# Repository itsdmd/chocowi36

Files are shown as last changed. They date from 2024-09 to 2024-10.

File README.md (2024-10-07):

# chocowi36

> A 36-key, low profile, wireless, split keyboard. Derived from [davidphilipbarr/Choc-Spaced-Corne](https://github.com/davidphilipbarr/Choc-Spaced-Corne), with the original design based on [Foostan's Corne](https://github.com/foostan/crkbd).

Finished build

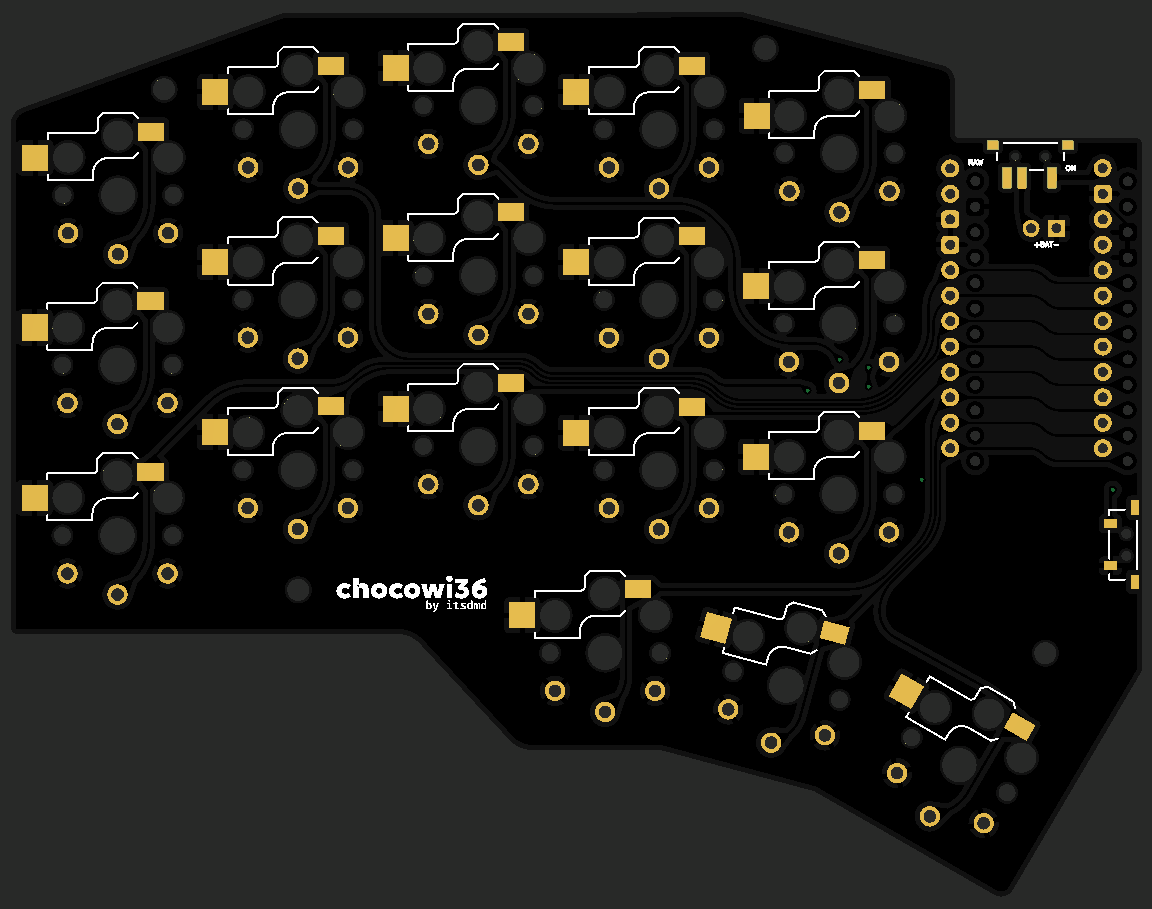
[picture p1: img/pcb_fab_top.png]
chocowi36 PCB Top - JLCPCB render
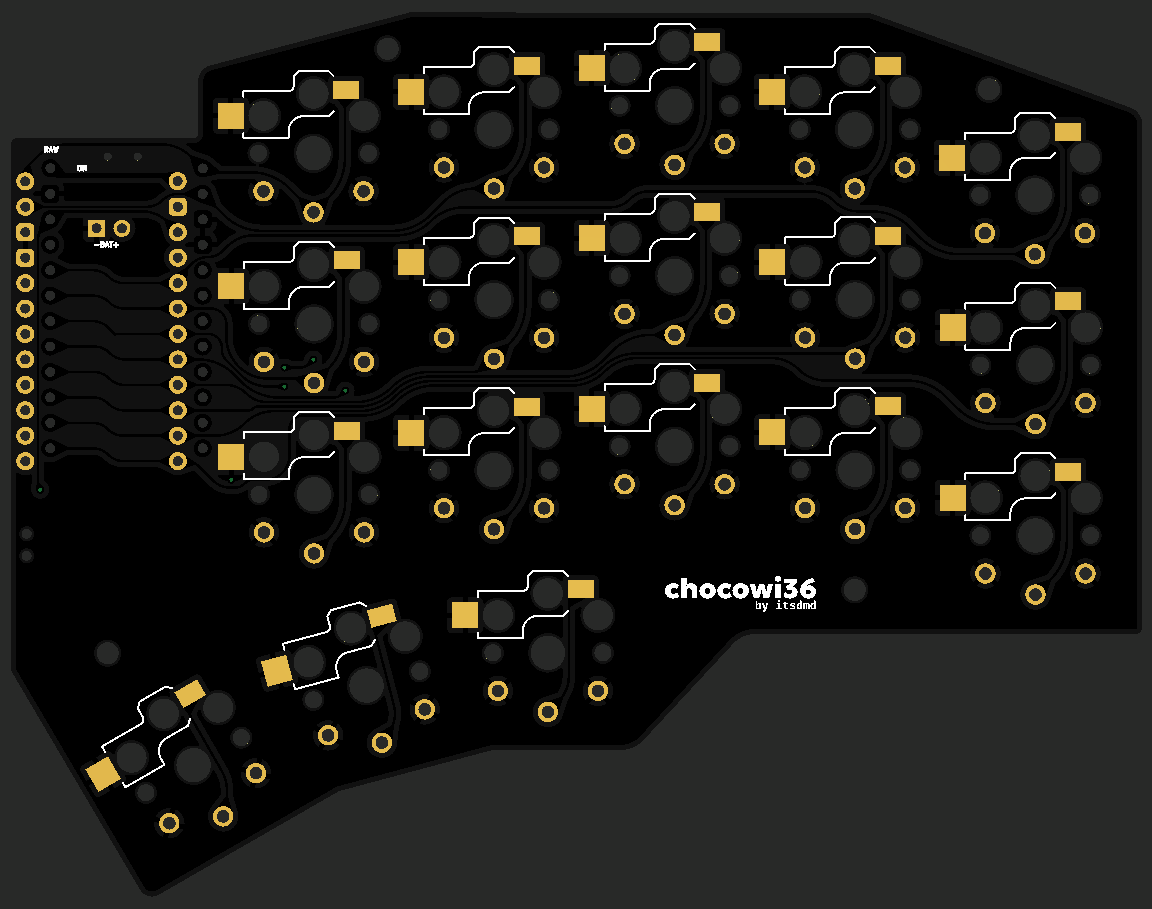
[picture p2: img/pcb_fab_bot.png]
chocowi36 PCB Bottom - JLCPCB render
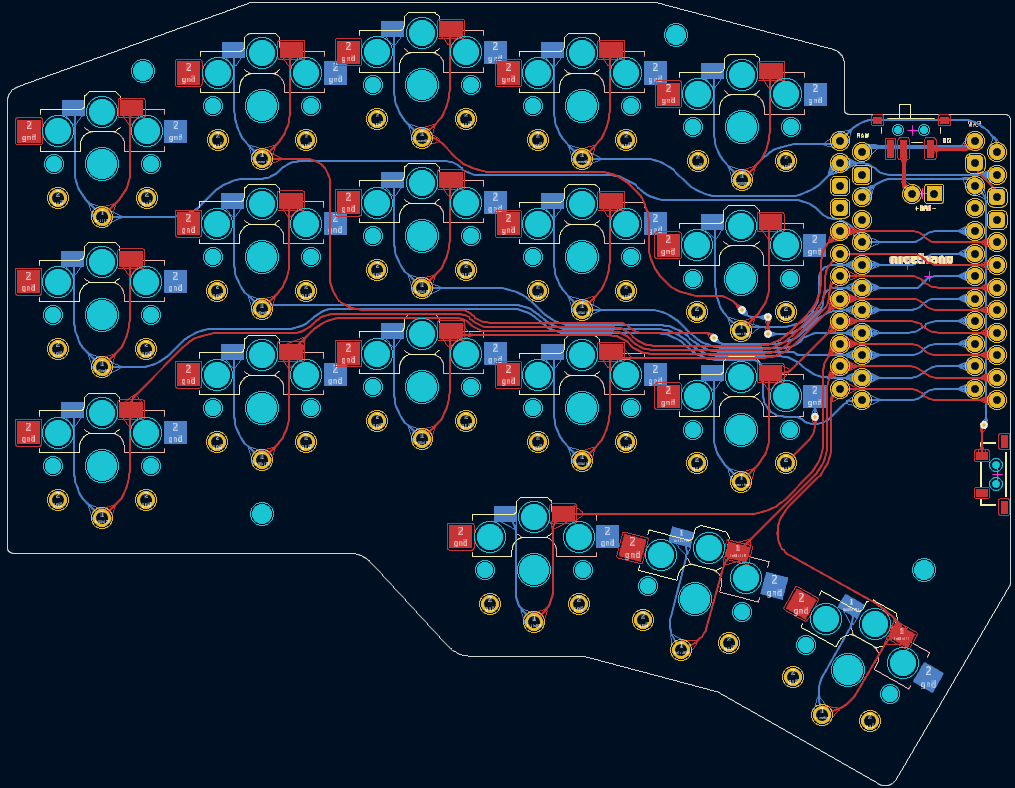
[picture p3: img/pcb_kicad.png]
chocowi36 PCB - KiCad render


## Changes

-   The PCB shape, dimensions and mounting holes' position are modified to personal preferences.
-   Battery onboard connector is replaced with through hole pads for better flexibility. Power switch is connected to the positive terminal of the battery instead of ground.
-   The outermost thumb key has been changed to a 1u key, and the splayed angle of the thumb cluster has been increased to 15 degrees.
-   Allow the nice!nano to be mounted with the USB port facing down for both halves for better MCB protection.
-   Support both hotswap and soldered switches. Only Choc v1 switches are supported.

## Case

The case for the keyboard can be found here: [OnShape document](https://cad.onshape.com/documents/46b39ce86a53def7590272f1/w/488db377576b09efc6e15f6f/e/8a81a5fcc0753b2088ec2435)

Finished build - Folded

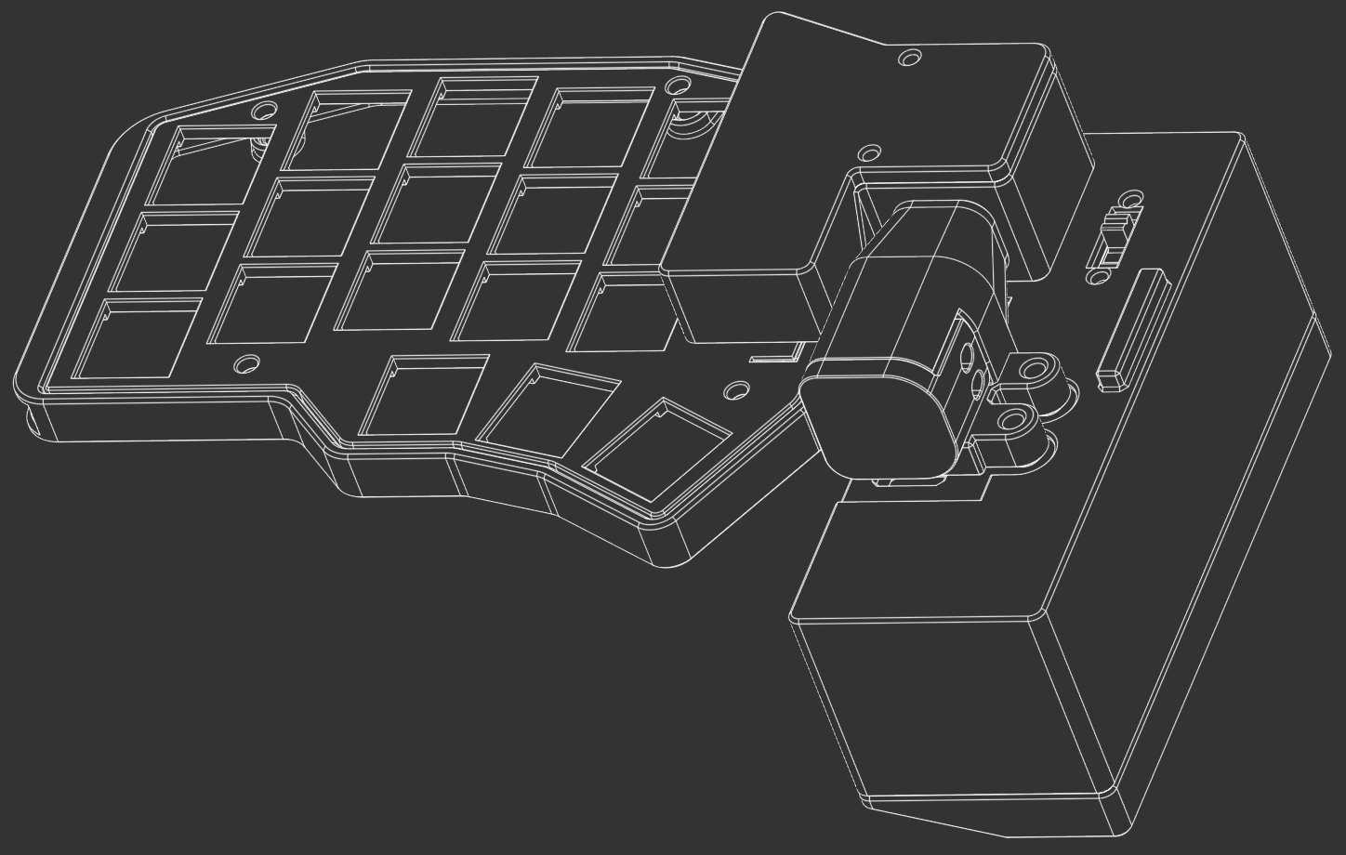
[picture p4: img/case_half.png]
chocowi36 Case - OnShape render
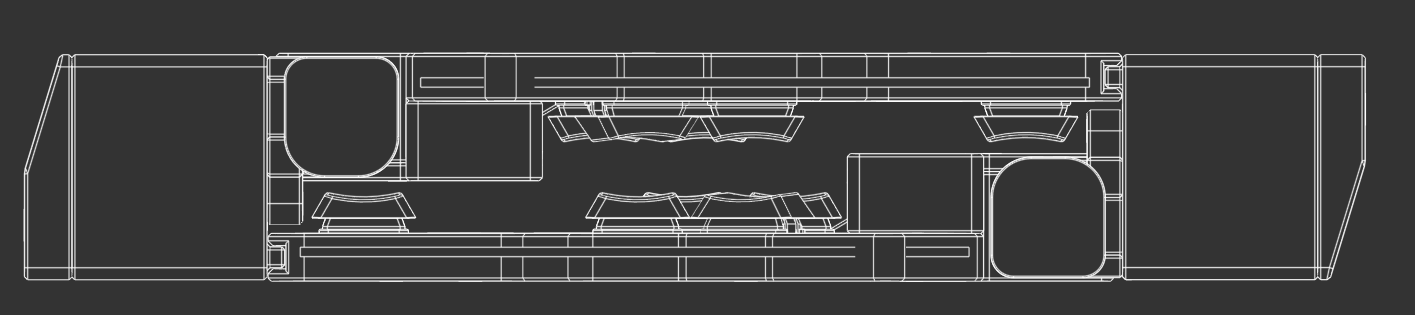
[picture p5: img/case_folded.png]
chocowi36 Case Folded - OnShape render


This case features a 5.5x2.1 DC power jack for connecting to a detachable Li-Ion battery enclosure. The provided enclosure is designed for storing a 21700 battery with a protection PCB attached to it. This enclosure can act as a tenting mechanism, or for locking the two keyboard halves in place when folded for travelling. Most parameters can be _slightly_ adjust without breaking the whole thing. The screw holes are 3.0mm in diameter (for housing M2 heat inserts), and default tolerance is 0.3-0.5mm.

## Firmware

ZMK shield definition of chocowi36 can be obtained [here](https://github.com/itsdmd/zmk-dongle/tree/N!N_v2/config/boards/shields/chocowi36). Please note that the definition files are written for the keyboard to be used with a third nice!nano as the central/dongle.

The provided files should only act as the boilerplate, please adjust the configurations according to your personal needs and preferences. You can create your own repo using the [template](https://github.com/itsdmd/zmk-dongle) and make further modifications.

## Notes

There are two versions of the PCB, one with [straight traces](./pcb/gerber/straight/straight.zip) and one with [curved traces](./pcb/gerber/rounded/rounded.zip). There are no major differences between the two, mostly just aesthetics.

## Disclaimer

This is a **personal project** and not affiliated with the original authors. The gerber file has been checked against JLCPCB's DFM checker and no critical error was found. All files (including firmware) are provided as-is, **without any warranty or support**.

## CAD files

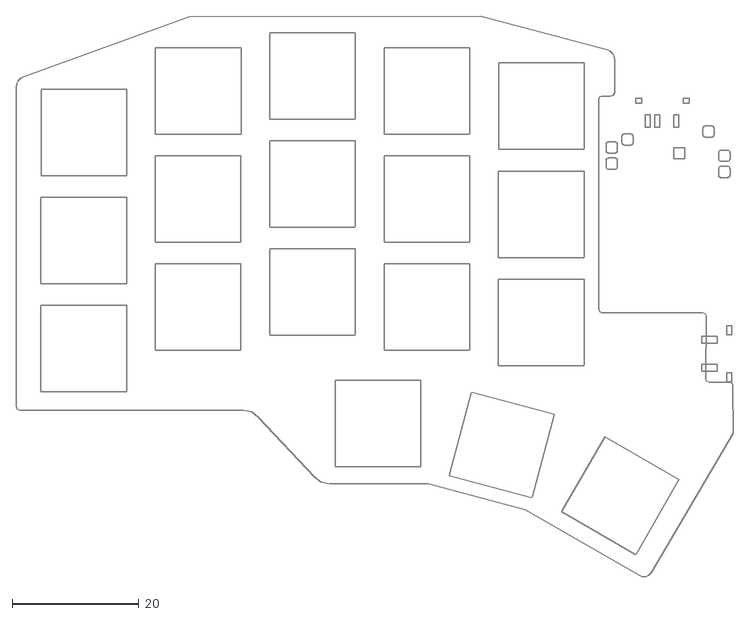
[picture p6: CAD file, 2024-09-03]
case/components/plate-brd.dxf
113.0 x 88.3

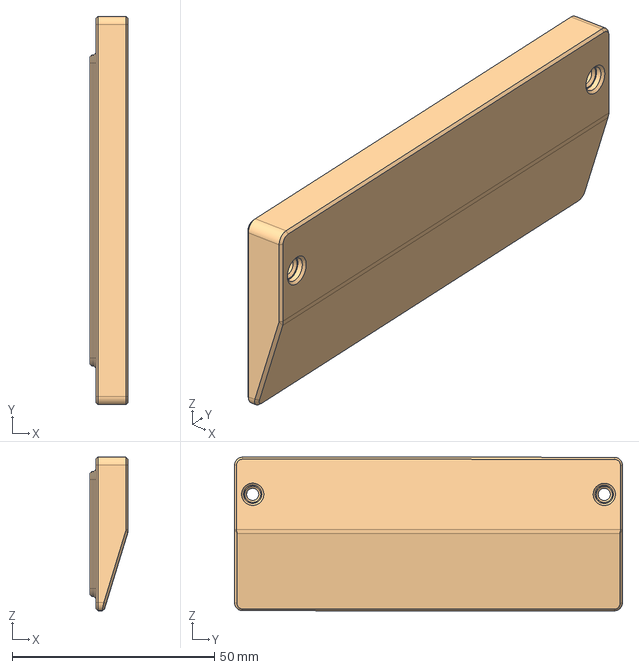
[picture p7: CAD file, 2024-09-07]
case/step/BattPack - Container Cover.step
9.53 x 96.0 x 38.0 mm

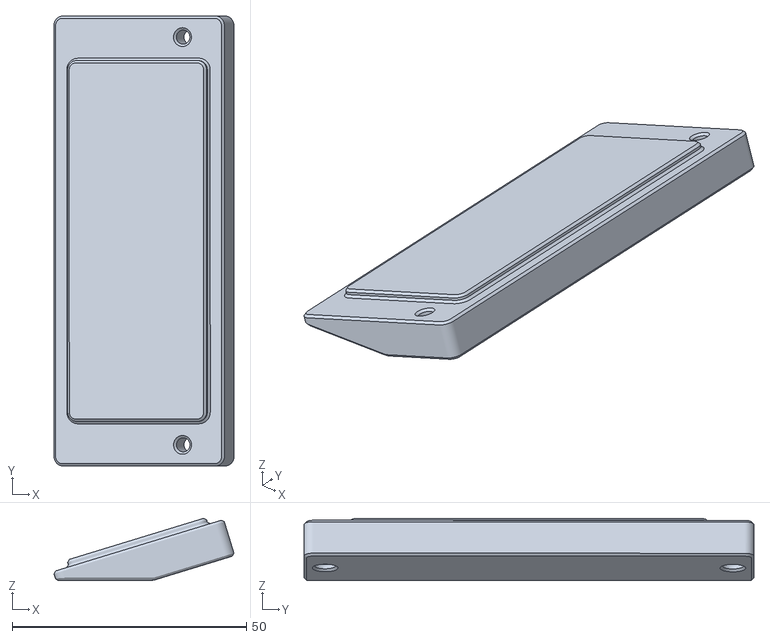
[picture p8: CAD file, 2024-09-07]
case/stl/L - BattPack - Container Cover.stl
38.4 x 96.0 x 13.3

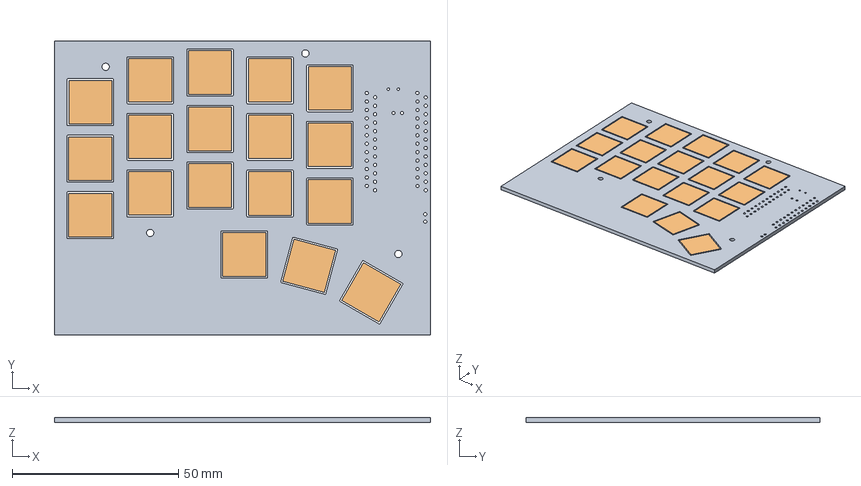
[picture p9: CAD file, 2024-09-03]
case/components/chocowi36-plate.step
113.1 x 88.4 x 1.60 mm

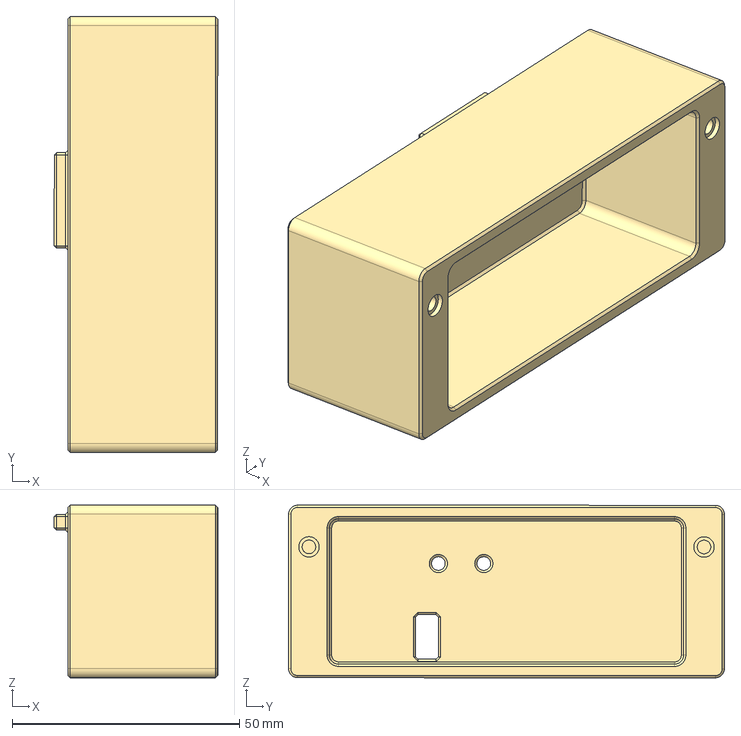
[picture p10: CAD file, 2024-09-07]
case/step/BattPack - Container.step
36.0 x 96.0 x 38.0 mm

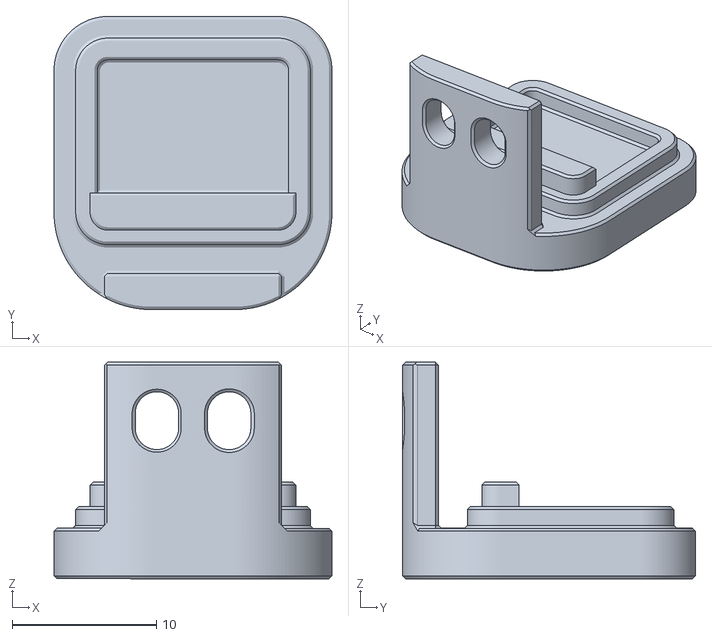
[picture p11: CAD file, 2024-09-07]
case/stl/L - BattPack - Connector Cover.stl
19.3 x 20.3 x 15.0

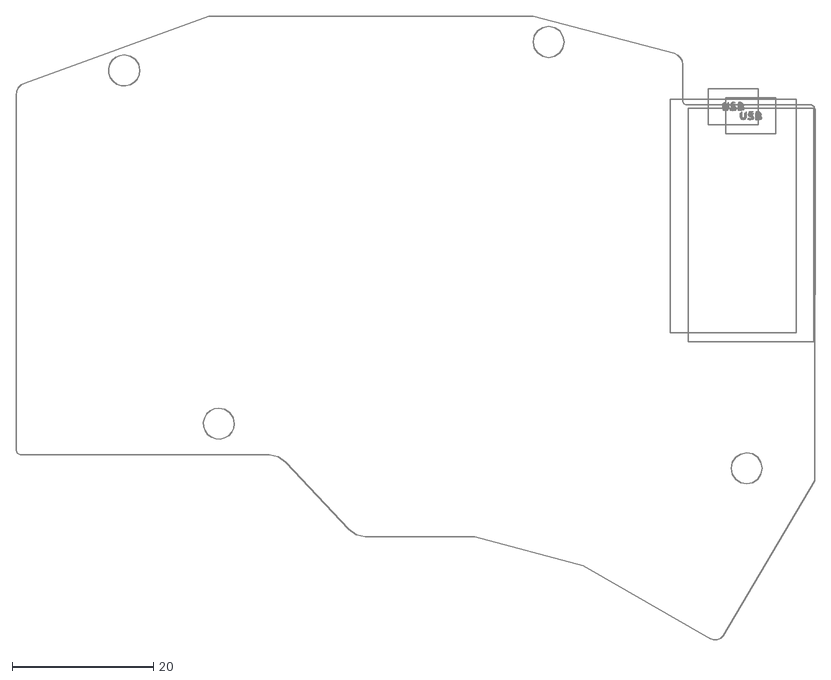
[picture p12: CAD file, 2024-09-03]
case/components/chocowi36-brd.dxf
113.1 x 88.3

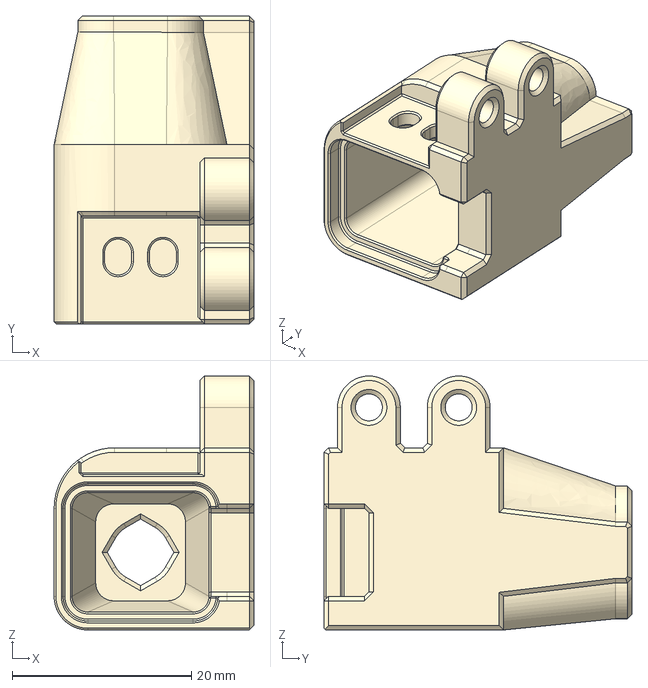
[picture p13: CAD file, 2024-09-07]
case/step/BattPack - Connector.step
22.3 x 34.3 x 28.3 mm

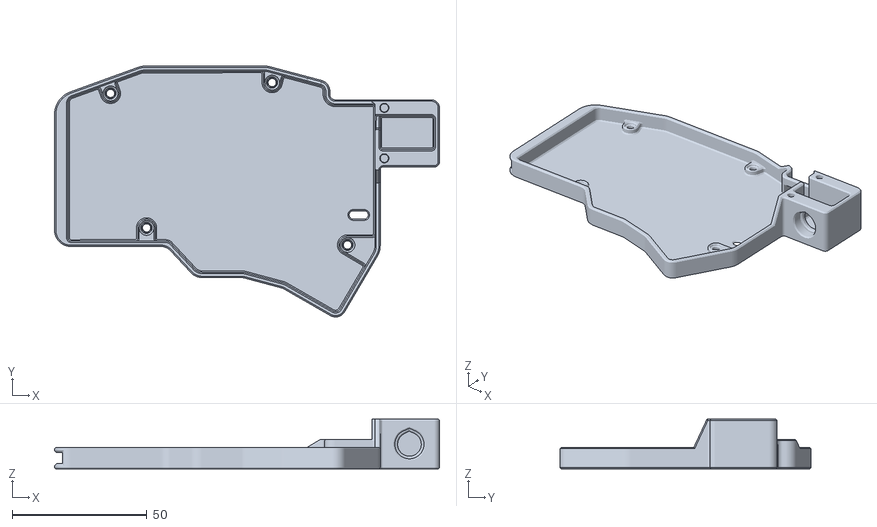
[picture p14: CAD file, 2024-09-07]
case/stl/L - Case.stl
143.1 x 93.3 x 18.5

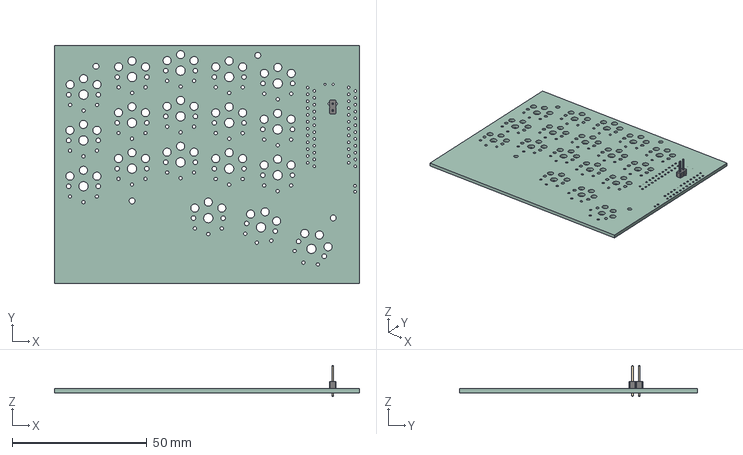
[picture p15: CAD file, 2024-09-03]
case/components/chocowi36.step
113.2 x 88.4 x 11.5 mm
PinHeader_1x02_P254mm_Vertical
chocowi36_PCB

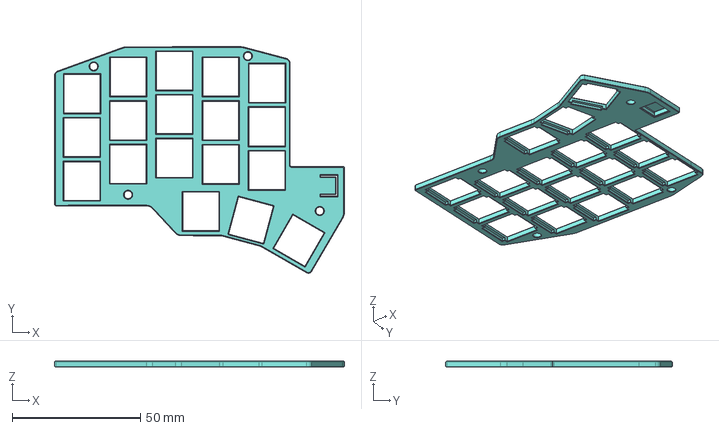
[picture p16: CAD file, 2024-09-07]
case/step/Plate.step
113.0 x 88.3 x 2.30 mm

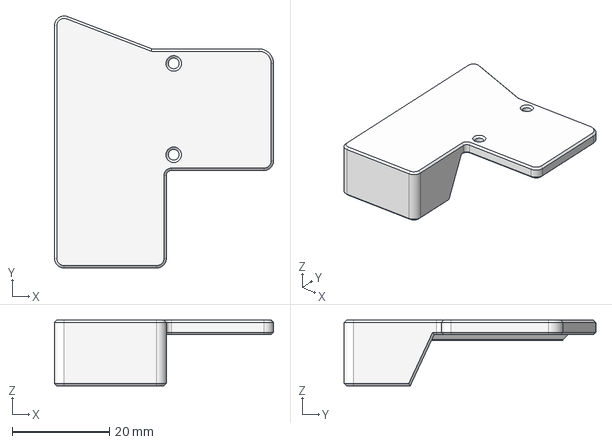
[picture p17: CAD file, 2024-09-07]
case/step/MCB Cover.step
45.0 x 51.7 x 13.5 mm

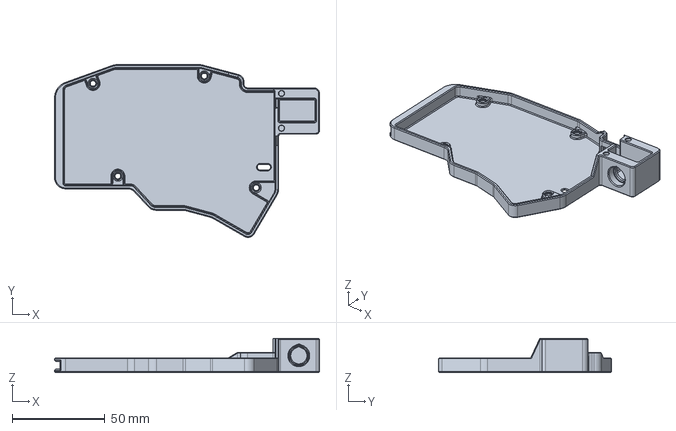
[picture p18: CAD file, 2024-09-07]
case/step/Case.step
143.1 x 93.3 x 18.5 mm

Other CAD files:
case/stl/L - BattPack - Container.stl
case/stl/L - Plate.stl
case/stl/R - BattPack - Container Cover.stl
case/step/BattPack - Connector Cover.step
case/stl/R - BattPack - Container.stl
case/stl/L - BattPack - Connector.stl
case/stl/L - MCB Cover.stl
case/stl/R - BattPack - Connector Cover.stl
case/stl/R - BattPack - Connector.stl
case/stl/R - Case.stl
case/stl/R - MCB Cover.stl
case/stl/R - Plate.stl

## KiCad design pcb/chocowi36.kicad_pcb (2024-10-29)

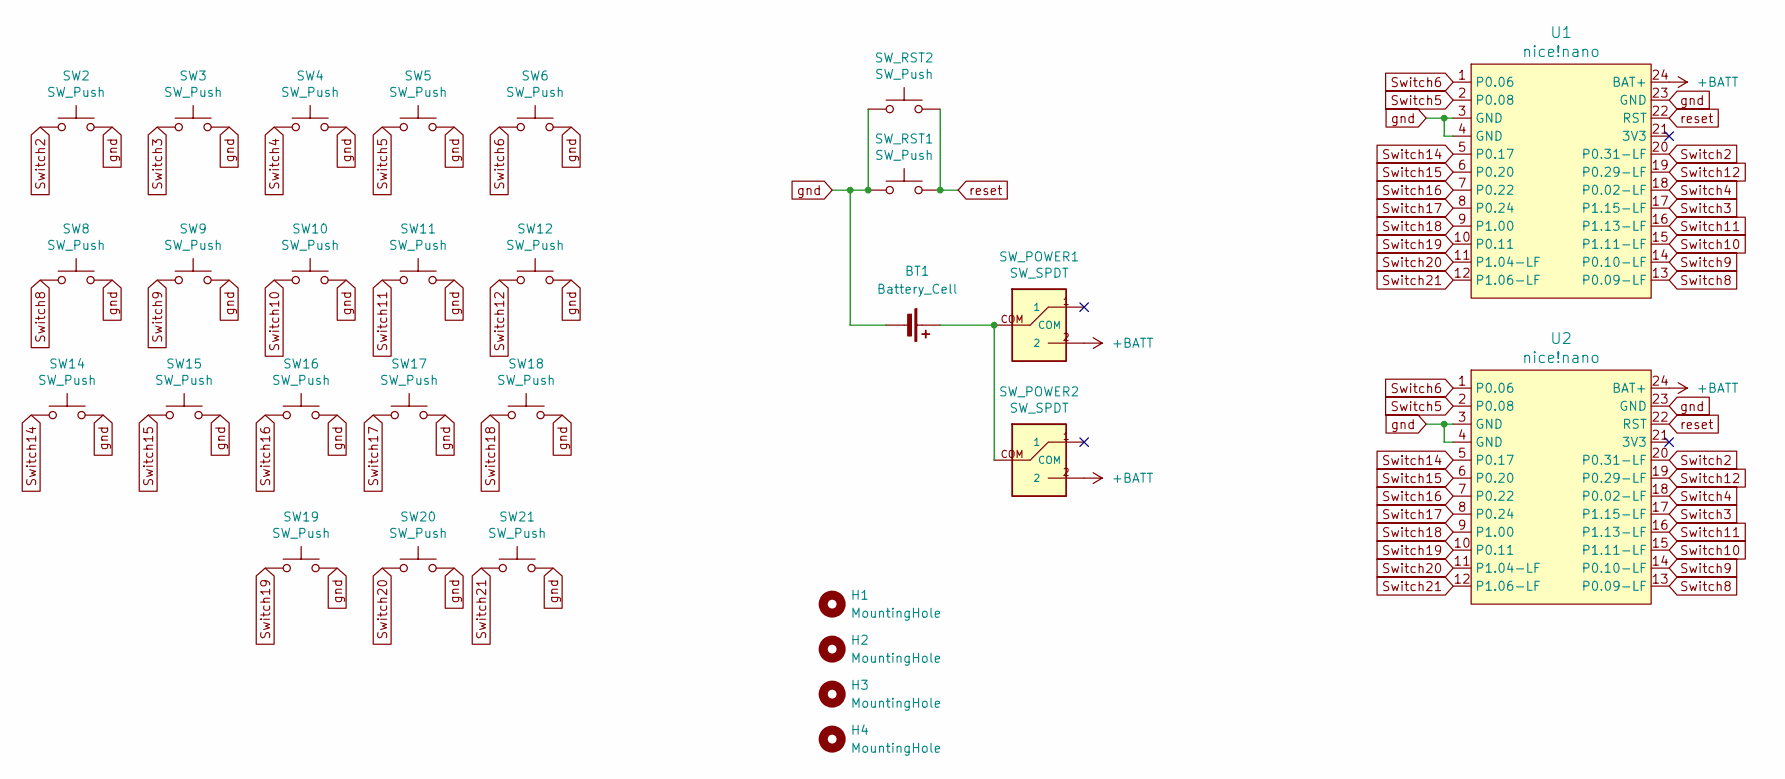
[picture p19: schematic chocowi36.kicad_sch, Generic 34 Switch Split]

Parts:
BT1: Battery_Cell; Battery_Pads-dual-side
H1, H2, H3, H4: MountingHole; MountingHole_2.2mm_M2
SW2, SW3, SW4, SW5, SW6, SW8, SW9, SW10, SW11, SW12, SW14, SW15, SW16, SW17, SW18, SW19, SW20, SW21: SW_Push; KS_Socket_Choc_optional_reversible
SW_POWER1, SW_POWER2: SW_SPDT; SW-S_MSK-12C02
SW_RST1, SW_RST2: SW_Push; SW-T_SPST_TL3342
U1, U2: nice!nano; MCB_nice-nano_flip

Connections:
+BATT: SW_POWER1.2, SW_POWER2.2, U1.24 (BAT+), U2.24 (BAT+)
unnamed: BT1.1 (+), SW_POWER1.COM, SW_POWER2.COM
Switch2: SW2.1, U1.20 (P0.31-LF), U2.20 (P0.31-LF)
Switch3: SW3.1, U1.17 (P1.15-LF), U2.17 (P1.15-LF)
Switch4: SW4.1, U1.18 (P0.02-LF), U2.18 (P0.02-LF)
Switch5: SW5.1, U1.2 (P0.08), U2.2 (P0.08)
Switch6: SW6.1, U1.1 (P0.06), U2.1 (P0.06)
Switch8: SW8.1, U1.13 (P0.09-LF), U2.13 (P0.09-LF)
Switch9: SW9.1, U1.14 (P0.10-LF), U2.14 (P0.10-LF)
Switch10: SW10.1, U1.15 (P1.11-LF), U2.15 (P1.11-LF)
Switch11: SW11.1, U1.16 (P1.13-LF), U2.16 (P1.13-LF)
Switch12: SW12.1, U1.19 (P0.29-LF), U2.19 (P0.29-LF)
Switch14: SW14.1, U1.5 (P0.17), U2.5 (P0.17)
Switch15: SW15.1, U1.6 (P0.20), U2.6 (P0.20)
Switch16: SW16.1, U1.7 (P0.22), U2.7 (P0.22)
Switch17: SW17.1, U1.8 (P0.24), U2.8 (P0.24)
Switch18: SW18.1, U1.9 (P1.00), U2.9 (P1.00)
Switch19: SW19.1, U1.10 (P0.11), U2.10 (P0.11)
Switch20: SW20.1, U1.11 (P1.04-LF), U2.11 (P1.04-LF)
Switch21: SW21.1, U1.12 (P1.06-LF), U2.12 (P1.06-LF)
gnd: BT1.2 (-), SW2.2, SW3.2, SW4.2, SW5.2, SW6.2, SW8.2, SW9.2, SW10.2, SW11.2, SW12.2, SW14.2, SW15.2, SW16.2, SW17.2, SW18.2, SW19.2, SW20.2, SW21.2, SW_RST1.1, SW_RST2.1, U1.3 (GND), U1.4 (GND), U1.23 (GND), U2.3 (GND), U2.4 (GND), U2.23 (GND)
reset: SW_RST1.2, SW_RST2.2, U1.22 (RST), U2.22 (RST)

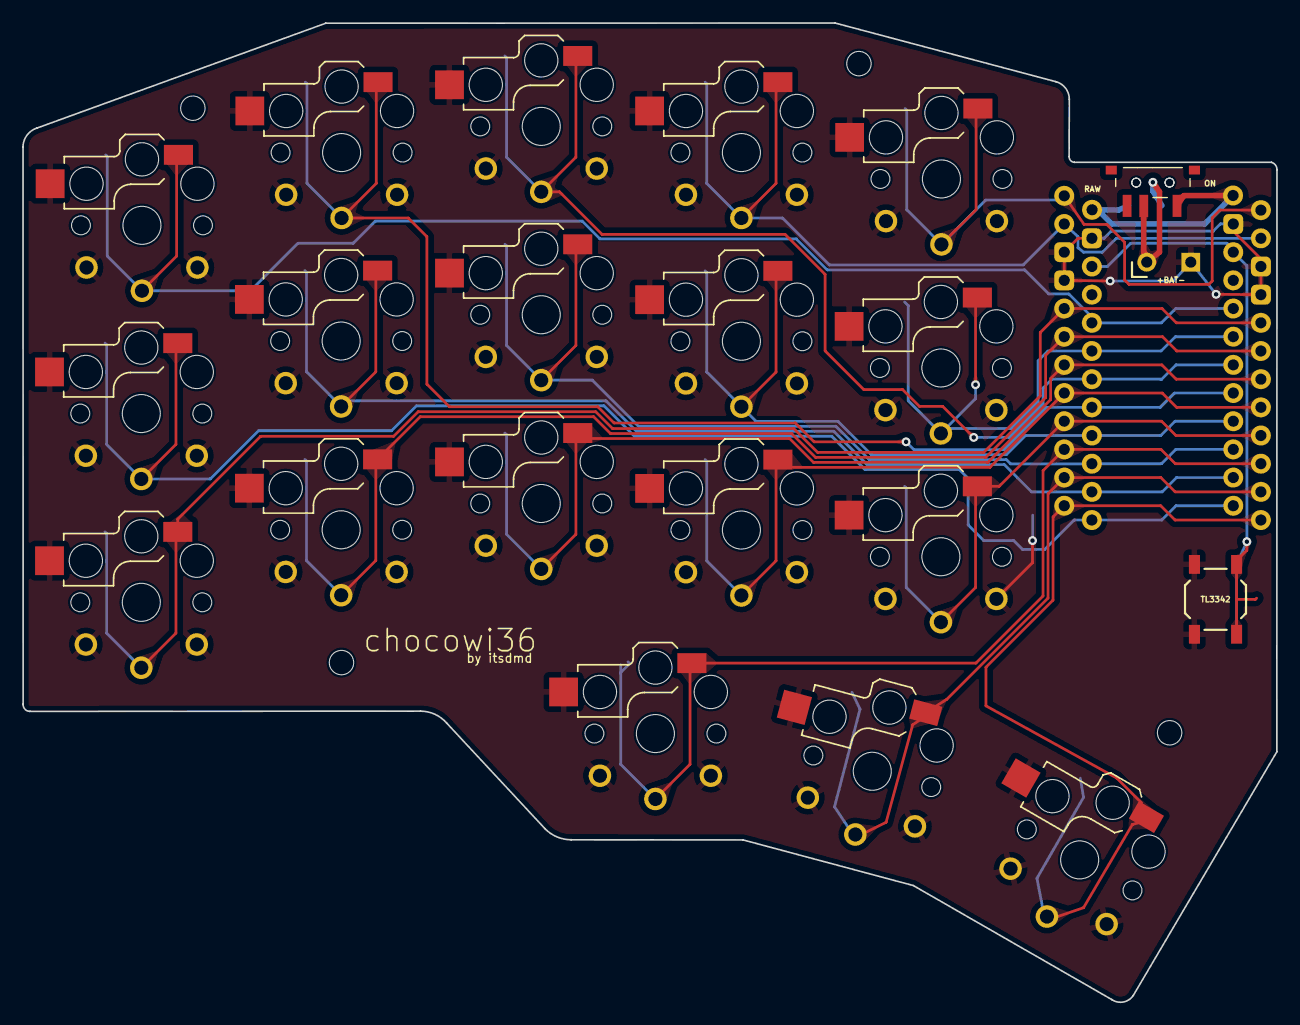
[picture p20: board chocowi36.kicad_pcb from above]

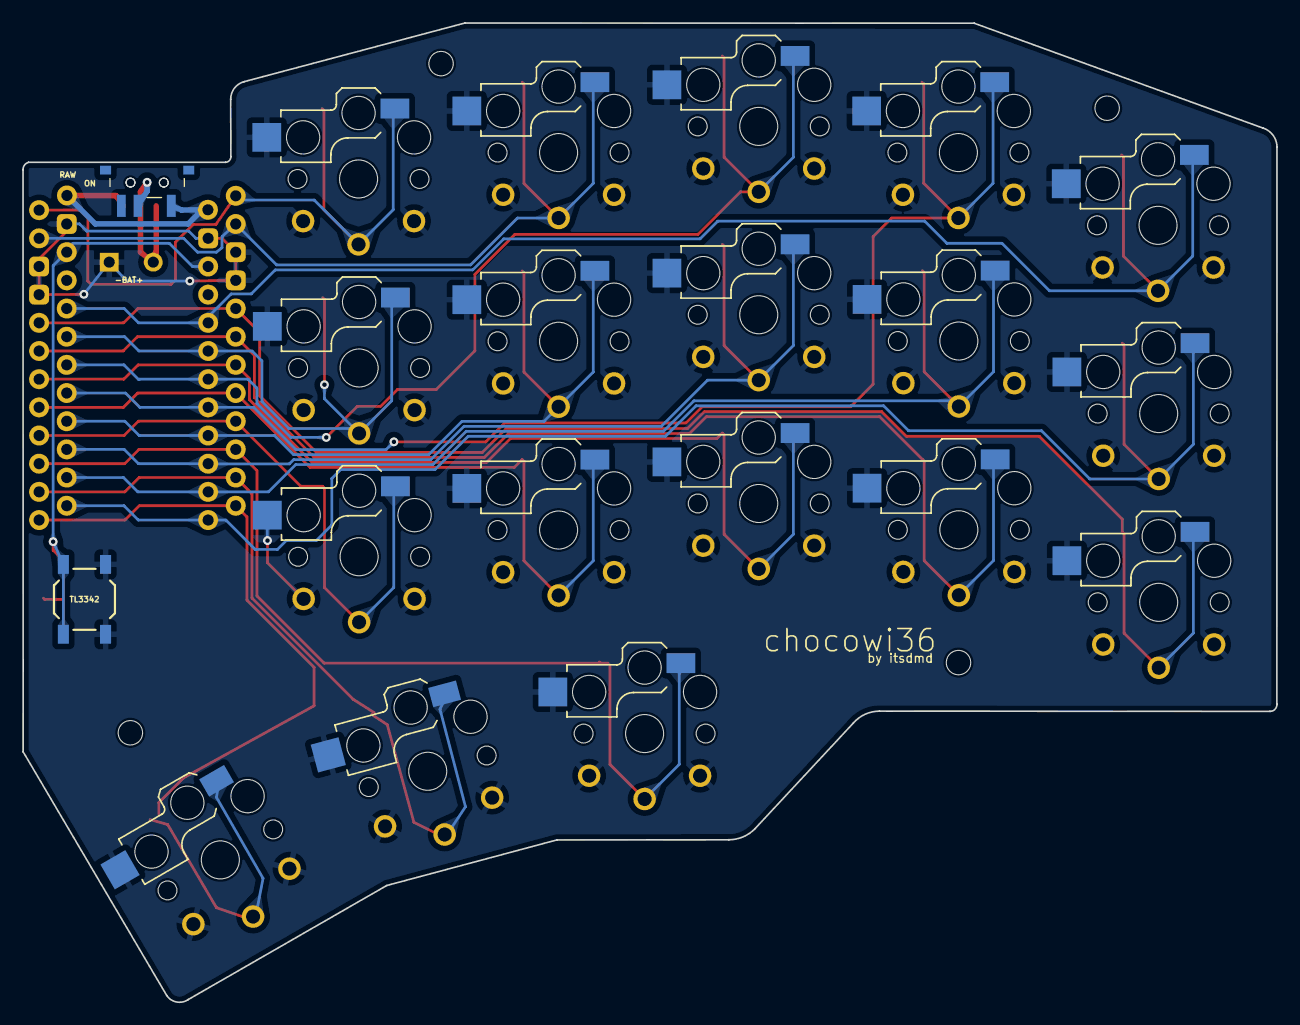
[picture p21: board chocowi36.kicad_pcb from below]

Board: 2 copper layers, 113.1 x 88.3 mm, 29 parts (3 on the bottom side), 22 nets.

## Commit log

2024-09-02 initial modifications
    [cc36-B_Cu.gbr, cc36-B_Mask.gbr, cc36-B_Paste.gbr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]
2024-09-02 rename to chocowi36
    [chocowi36-B_Cu.gbr, chocowi36-B_Mask.gbr, chocowi36-B_Paste.gbr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]
2024-09-02 small changes + update doc
    [chocowi36-B_Cu.gbr, chocowi36-B_Mask.gbr, chocowi36-B_Paste.gbr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]
2024-09-02 small update
    [chocowi36-brd.dxf, chocowi36-min.dxf, chocowi36-rounded.step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]
2024-09-02 adjust thumb cluster
    [chocowi36-B_Cu.gbr, chocowi36-B_Mask.gbr, chocowi36-B_Paste.gbr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]
2024-09-03 fix thumb cluster
    [chocowi36-B_Cu.gbr, chocowi36-B_Mask.gbr, chocowi36-B_Paste.gbr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]
2024-09-06 add case step & stl files
    [BattPack - Connector Cover.step, BattPack - Connector Cover.stl, BattPack - Connector.step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]
2024-09-07 update case design
    [BattPack - Connector Cover.step, BattPack - Connector Cover.stl, BattPack - Connector.step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]
2024-09-09 add case image
2024-10-29 update routing to support placing tactile switches on both sides
    [chocowi36-B_Cu.gbr, chocowi36-B_Mask.gbr, chocowi36-B_Paste.gbr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]
